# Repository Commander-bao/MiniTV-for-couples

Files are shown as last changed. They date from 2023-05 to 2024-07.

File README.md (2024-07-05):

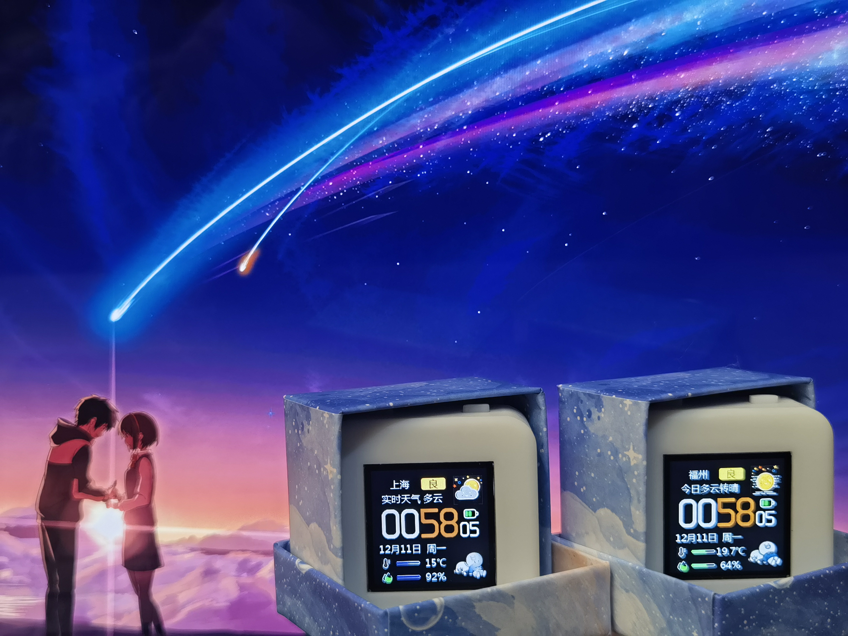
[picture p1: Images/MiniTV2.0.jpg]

# 基于ESP32的情侣小电视
## 0.关于本项目
本项目是个人的第一个软硬件项目，经过了约两个月断断续续的开发完成了现在的版本，其中PCB和外壳完全由自己设计，软件部分的代码在B站up主指针阿飞的基础上进行了修改。本项目的原理图和PCB基于嘉立创eda绘制，并在嘉立创平台上打样；外壳模型使用SketchUp2019设计；代码基于VScode上的插件PlatformIO进行开发。  
该小电视目前具备的功能有：天气时钟、电量显示、纪念日页、情侣互动、动画切换、亮度调节、快速配网。欢迎在本人的基础上实现更多的功能。
## 1.硬件打样说明
最新版本的PCB制板文件在Hardware/情侣小电视V2.1目录下，可在嘉立创平台上进行免费打样
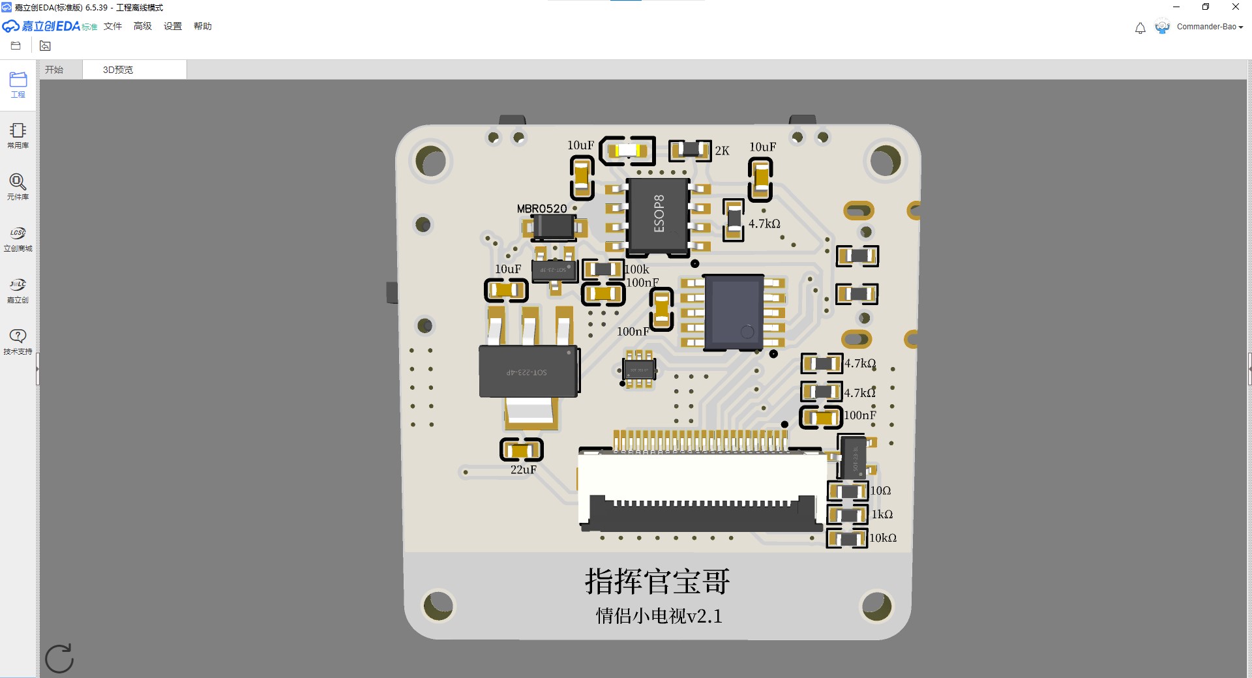
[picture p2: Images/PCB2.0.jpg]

最新版本的外壳文件在3D Model文件夹下，需要注意的是：如果不使用fdm打印机而使用光固化打印机，请选择高精度文件，二代小电视请选择2.0版本的外壳。
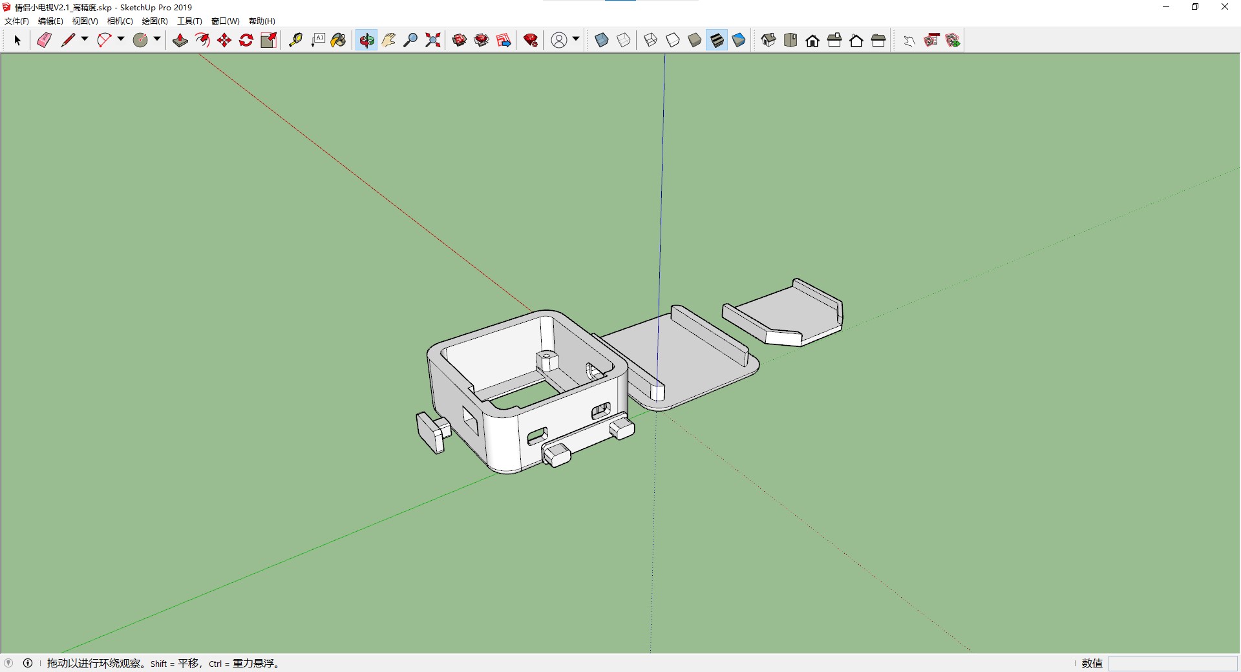
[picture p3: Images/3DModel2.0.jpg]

## 2.固件编译说明
烧录前请先在VScode上配置好PlatformIO插件，本项目最新的代码文件压缩包为Software文件夹下的LoveTV2.0.zip文件，解压后复制到自己本地的PlatformIO工程目录下即可打开。
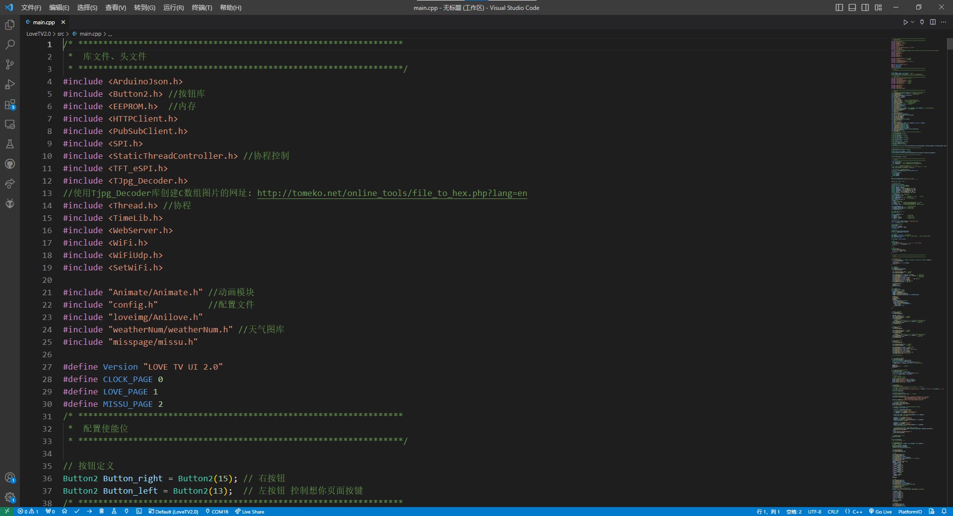
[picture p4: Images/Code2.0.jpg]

编译生成的固件以及其他相应固件在Firmware文件夹下，可通过乐鑫官方的烧录软件进行烧录
## 3.元件采购说明
绝大部分的元器件都可以在立创商城购买到，**注意原理图中的AMS1117芯片要换成BL9110芯片**  
本人采购的电池型号为602530，嘉立创上买不到的元器件可以参考以下链接购买：
- 显示屏链接：https://item.taobao.com/item.htm?id=565306950948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  
- Type-c链接：https://item.taobao.com/item.htm?id=573090887123&spm=a1z0d.6639537/tb.1997196601.4.3c317484soud9F  
- 主控芯片链接：https://item.taobao.com/item.htm?id=634424428305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  
- FPC连接器链接：https://item.taobao.com/item.htm?id=552629356951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  
- 滑动开关链接：https://item.taobao.com/item.htm?id=569513203579&spm=a1z0d.6639537/tb.1997196601.261.3c317484soud9F  
## 4.产品使用说明
（1.x版本）  
1.左侧的开关控制小电视开关机，仅关机状态可充电，开机状态可烧录  
2.左按钮按第一下配网，按第二下重启；右按钮切换显示动画  
3.第一次使用/左按钮按下/网络连接失败的情况下都会弹出配网页面，请在手机WiFi中找到并连接“情侣小电视”，分别输入网络名称、密码、所在城市后点击保存，小电视会自动重启  
（2.x版本）  
1.左侧开关控制小电视开关机，插上电源线即可充电，开机状态可烧录  
2.单击左按钮跳出情侣日页面，双击左按钮发送想你啦，长按左按钮重启；单击右按钮调节屏幕亮度，双击右按钮切换屏幕动画，长按右按钮配网  
3.第一次使用/右按钮长按/网络连接失败的情况下都会弹出无网络提示，请在手机WiFi中找到并连接“情侣小电视”，分别输入网络名称、密码、所在城市后点击保存，小电视会自动重启  
## 2023.12.07更新说明
1.小电视的硬件更新到了2.1.1版本，把microusb接口换成了更常用的type-c  
2.小电视的外壳更新到了2.0版本，适配新的type-c的接口，更美观  
3.小电视的代码更新到了2.0版本，能够实现和对象互相通信

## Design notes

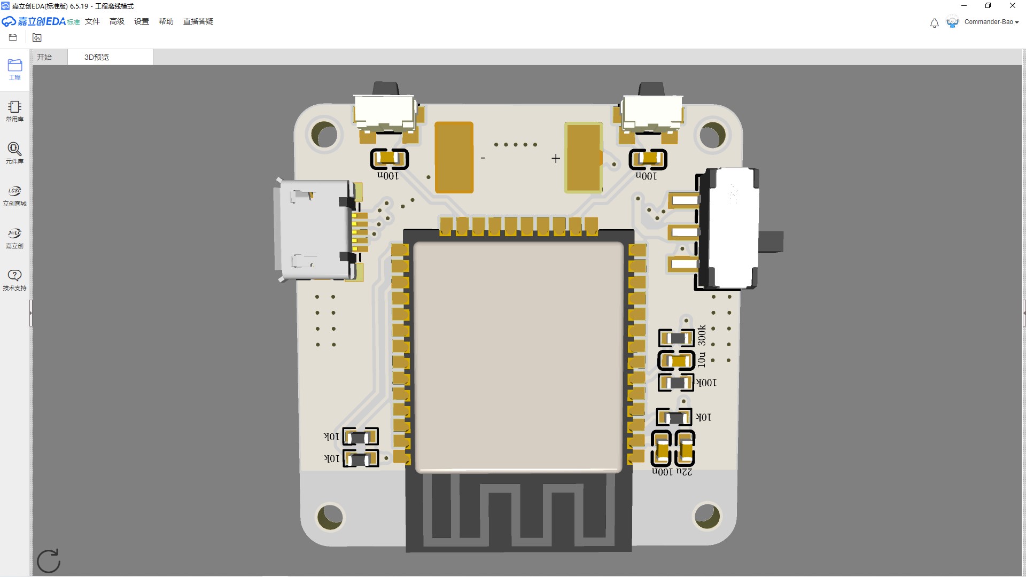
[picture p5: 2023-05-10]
Images/PCB2.jpg

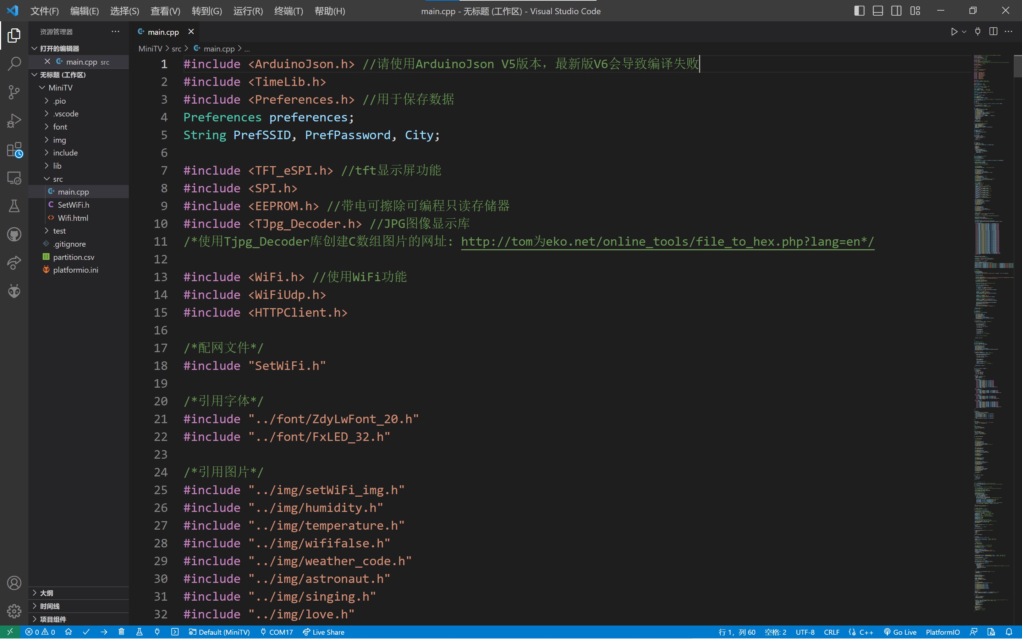
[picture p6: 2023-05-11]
Images/Code.jpg

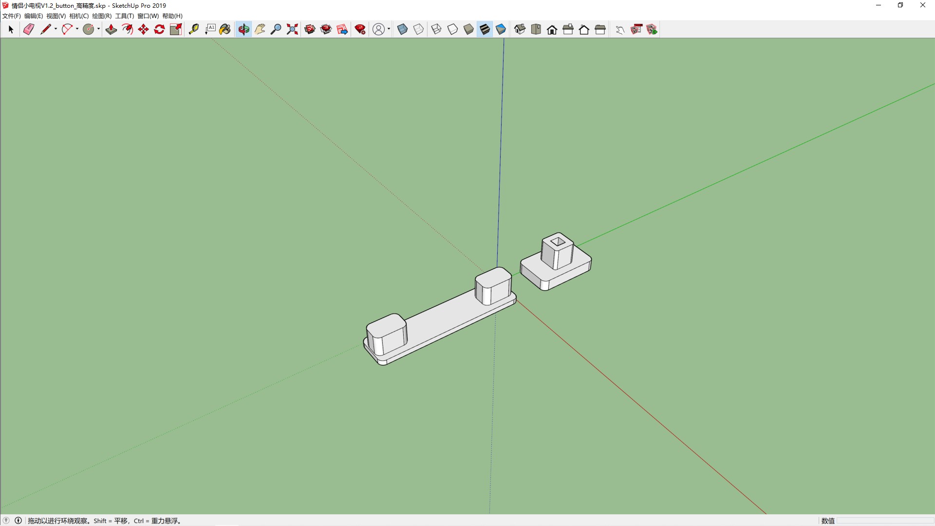
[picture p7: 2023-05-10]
Images/3DModel2.jpg

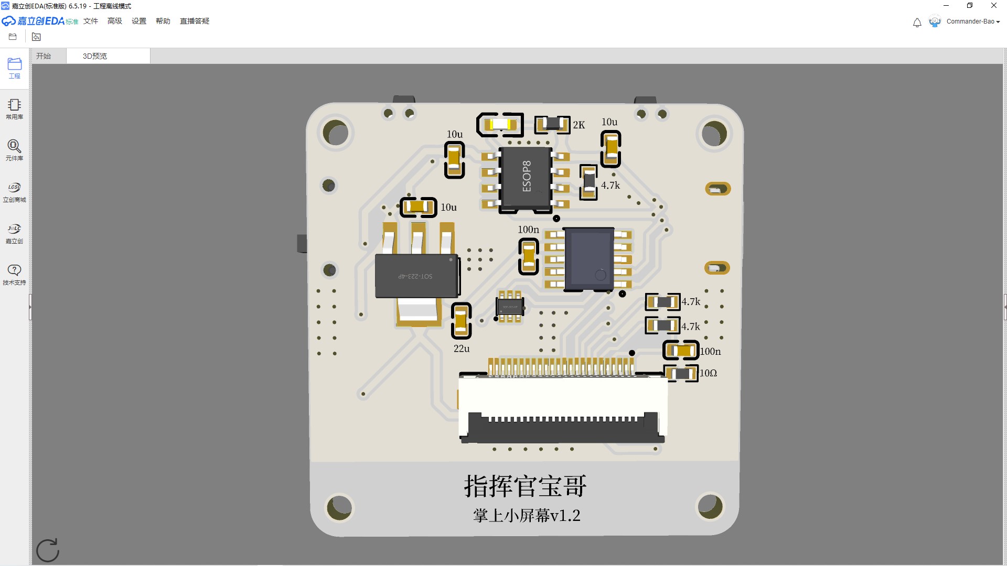
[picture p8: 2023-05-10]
Images/PCB1.jpg

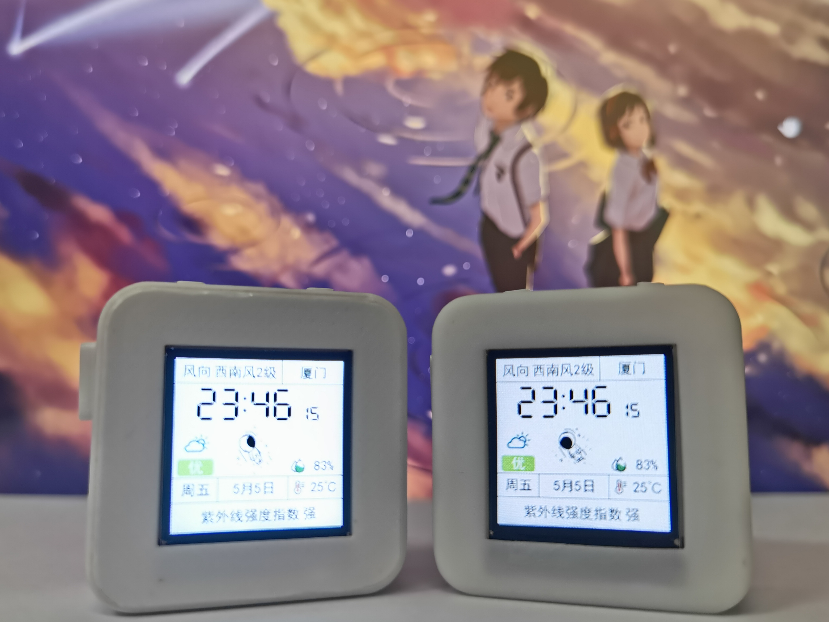
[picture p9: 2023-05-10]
Images/MiniTV.jpg

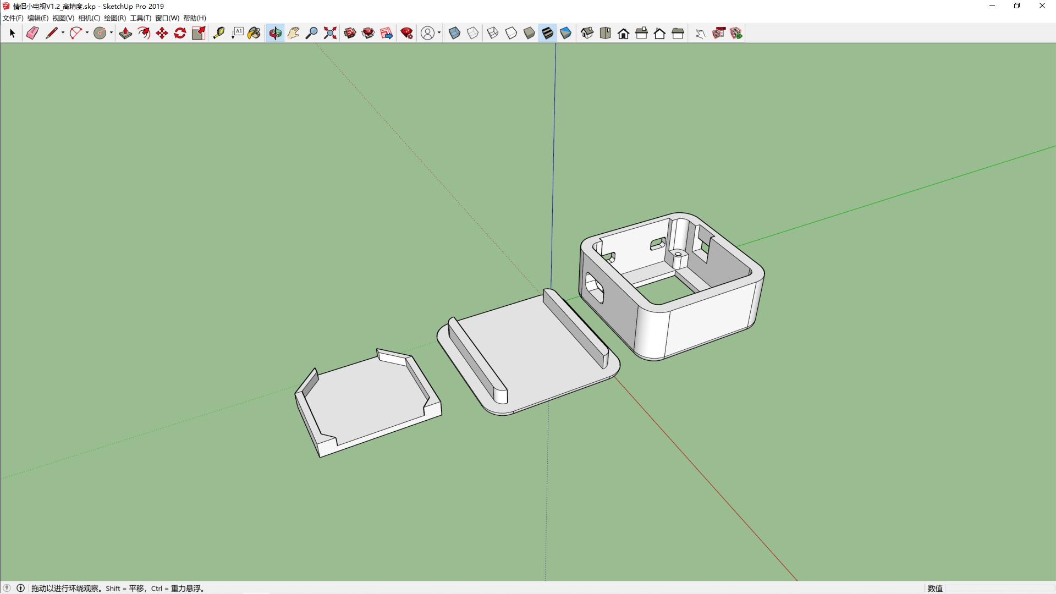
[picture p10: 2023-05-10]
Images/3DModel1.jpg

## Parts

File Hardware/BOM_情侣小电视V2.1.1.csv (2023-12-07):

ID | Name | Designator | Footprint | Quantity | Manufacturer Part | Manufacturer | Supplier | Supplier Part | Price
1 | JS102011SAQN | SW2 | SW-SMD_JS102011SAQN | 1 | JS102011SAQN | C&K | LCSC
2 | SS8050 | U7 | SOT-23-3_L2.9-W1.6-P1.90-LS2.8-BR | 1 | SS8050-MS | MSKSEMI(美森科) | LCSC
3 | 1kΩ | R10 | R0603 | 1 | RT0603BRD071KL | YAGEO(国巨) | LCSC
4 | 10kΩ | R1,R2,R3,R14 | R0603 | 4 | SY0603JN10KP | SANYEAR(叁叶源) | LCSC
5 | 10Ω | R15 | R0603 | 1 | SY0603JN10KP | SANYEAR(叁叶源) | LCSC
6 | 5.1kΩ | R12,R13 | R0603 | 2 | CR0603F5K10P05Z | EVER OHMS(天二科技) | LCSC
7 | 100k | R5 | R0603 | 1 | SY0603JN10KP | SANYEAR(叁叶源) | LCSC
8 | 100nF | C7,C3,C12,C1,C10,C11 | C0603 | 6 | VJ0603Y104KXJAC | VISHAY(威世) | LCSC
9 | MBR0520 | D1 | SOD-123_L2.8-W1.8-LS3.7-RD | 1 | MBR0520 | CJ(江苏长电/长晶) | LCSC
10 | SI2305 | Q1 | SOT-23-3_L2.9-W1.3-P1.90-LS2.4-BR | 1 | SI2305 | Hottech(合科泰) | LCSC
11 | 10uF | C4,C6,C8,C9 | C0603 | 4 | GRM188R61C106KAALD | muRata(村田) | LCSC
12 | 22uF | C5,C2 | C0603 | 2 | 0603X226M100NT | FH(风华) | LCSC
13 | 4.7kΩ | R4,R6 | R0603 | 2 | RMC06034K7FN | Tyohm(幸亚电阻) | LCSC
14 | 4.7kΩ | R9 | R0603 | 1 | RMC06031.2K1%N | Tyohm(幸亚电阻) | LCSC
15 | 2K | R7 | R0603 | 1 | AC0603FR-072KL | YAGEO(国巨) | LCSC
16 | KH-FG0.5-H2.0-24PIN | CN1 | FPC-SMD_KH-FG0.5-H2.0-24PIN | 1 | KH-FG0.5-H2.0-24PIN | kinghelm(金航标) | LCSC
17 | UMH3NTN | Q2 | SOT-363_L2.0-W1.3-P0.65-LS2.1-TL | 1 | UMH3NTN | ROHM(罗姆) | LCSC
18 | AMS1117-3.3 | U2 | SOT-223-3_L6.5-W3.4-P2.30-LS7.0-BR | 1 | AMS1117-3.3 | AMS | LCSC
19 | TP4056_C5311018 | U8 | ESOP-8_L4.9-W3.9-P1.27-LS6.0-BL-EP | 1 | TP4056 | TECH PUBLIC(台舟) | LCSC
20 | CH340K | U3 | CH340K | 1 | CH340K | WCH(南京沁恒)
21 | 300kΩ | R11,R8 | R0603 | 2 | AR03BTCX1003 | Viking(光颉) | LCSC
22 | TYPE-C-16PIN | USB1 | TYPE-C-SMD_TYPE-CF3.1 | 1 | TYPE-C-2.0-16PIN-SMT-3 | CIKI(皓富) | LCSC
23 | ESP32-WROOM-32E-N16 | U1 | WIFI-SMD_ESP32-WROOM-32E | 1 | ESP32-WROOM-32E-N16 | ESPRESSIF 乐鑫 | LCSC
24 | TS24CA | BUTTON1,BUTTON2 | SW-SMD_TS24CA | 2 | TS24CA | SHOU HAN(首韩) | LCSC

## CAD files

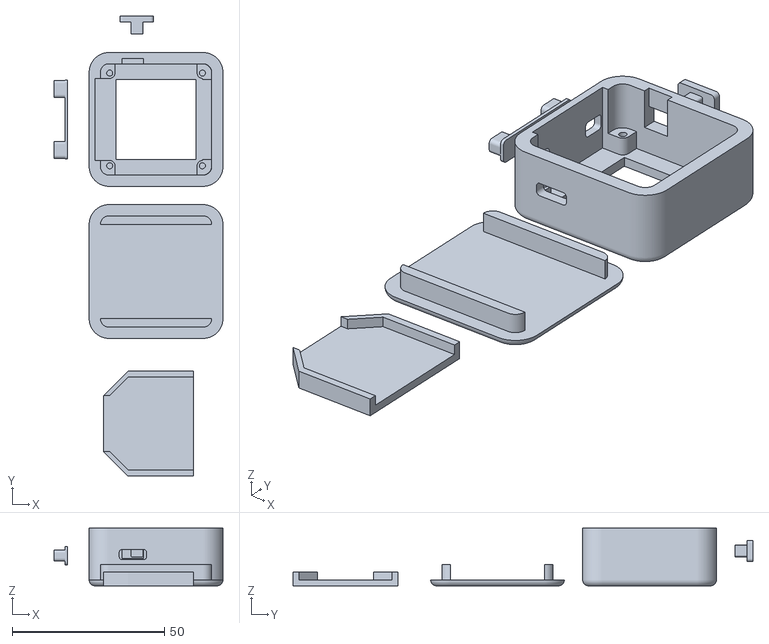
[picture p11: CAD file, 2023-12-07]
3D Model/情侣小电视Version2.0.stl
55.6 x 151.2 x 19.0

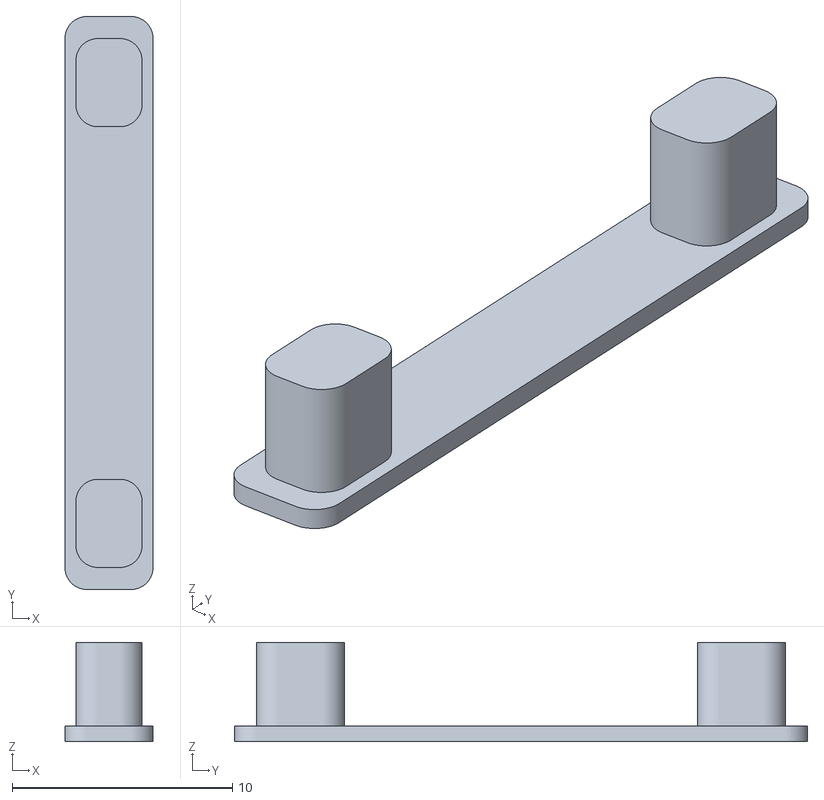
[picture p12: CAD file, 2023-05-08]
3D Model/情侣小电视按钮.stl
4.00 x 26.0 x 4.50

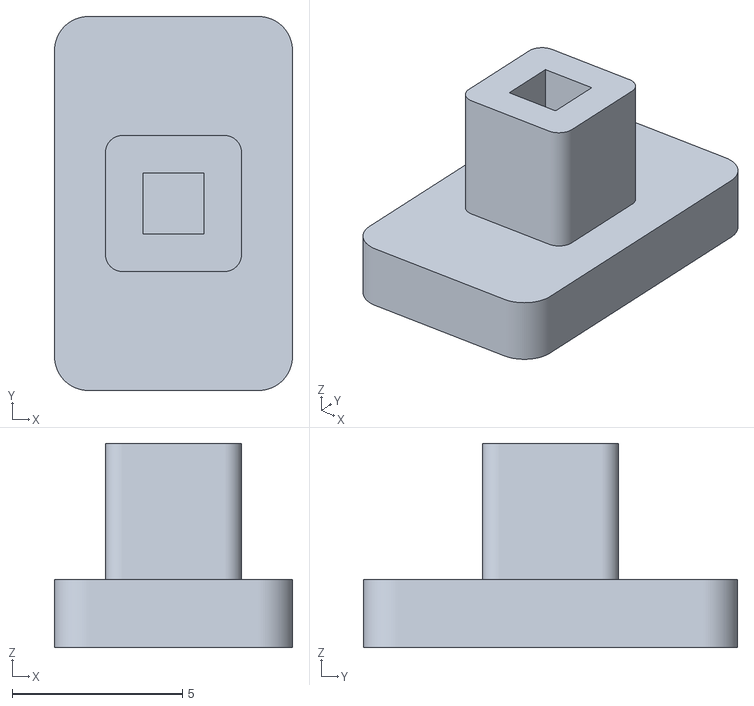
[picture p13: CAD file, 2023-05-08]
3D Model/情侣小电视开关_高精度.stl
7.00 x 11.0 x 6.00

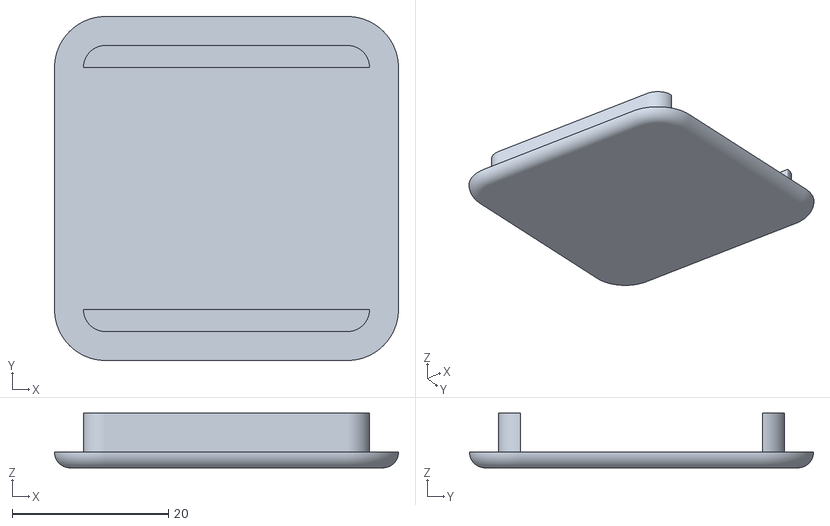
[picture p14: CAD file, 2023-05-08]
3D Model/情侣小电视下_高精度.stl
44.0 x 44.0 x 7.00

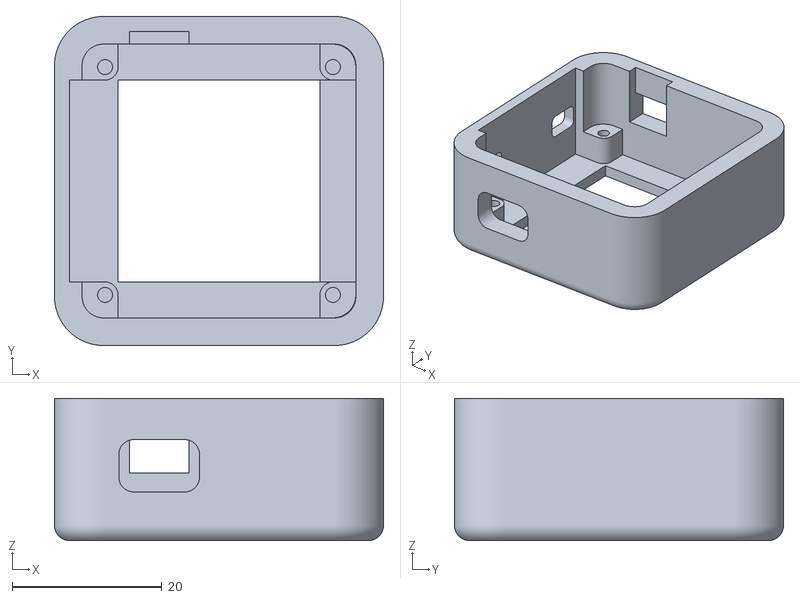
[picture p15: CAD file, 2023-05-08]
3D Model/情侣小电视上.stl
44.0 x 44.0 x 19.0

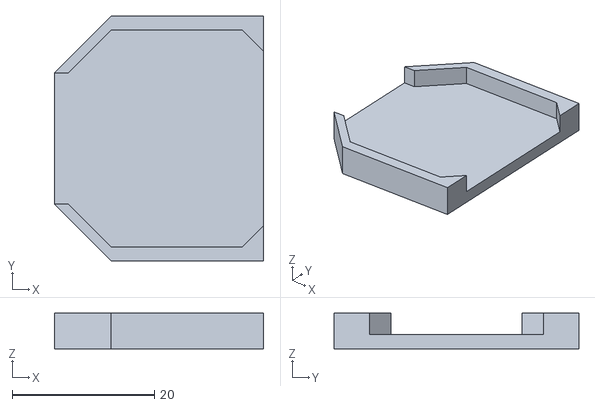
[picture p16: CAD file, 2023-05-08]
3D Model/情侣小电视中.stl
29.5 x 34.5 x 5.00

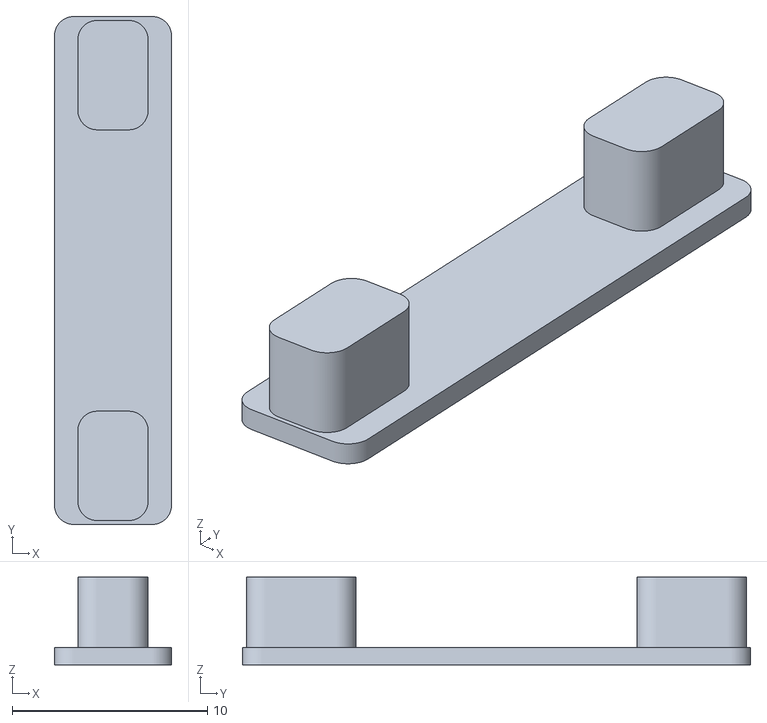
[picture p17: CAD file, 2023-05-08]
3D Model/情侣小电视按钮_高精度.stl
6.00 x 26.0 x 4.50

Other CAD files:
3D Model/情侣小电视开关.stl
3D Model/情侣小电视下.stl

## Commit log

2023-05-08 update Software
    [partition.csv]
2023-05-08 去掉了不必要的变量，更改了底部生活信息的显示
2023-05-08 update 3D Model
    [情侣小电视上.stl, 情侣小电视下.stl, 情侣小电视下_高精度.stl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]
2023-05-09 更换电量显示图片
    将原来的电量图片换成卡通的电量图片
2023-05-09 更新电量图片显示位置
2023-05-09 更改左按钮功能
    将左按钮功能改成第一下配网、第二下重启
2023-05-17 更新说明
2023-08-23 Add BOM
    [BOM_情侣小电视V1.2.csv]
2023-10-10 修正第一次烧录代码时反复重启的bug
2023-12-07 小电视第二代说明
2024-01-04 更新小电视2.x版本的使用说明
2024-01-20 更新2.0版本文档说明
2024-01-20 更新图片
2024-01-23 优化文档格式
2024-01-23 优化文档结构
2024-07-05 修正显示屏链接
